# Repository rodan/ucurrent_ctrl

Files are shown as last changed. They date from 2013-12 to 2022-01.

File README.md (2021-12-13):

## µCurrent controller

a MSP430F5510 based project that controls the power delivery to Dave L. Jones's [µCurrent](https://www.eevblog.com/projects/ucurrent/)

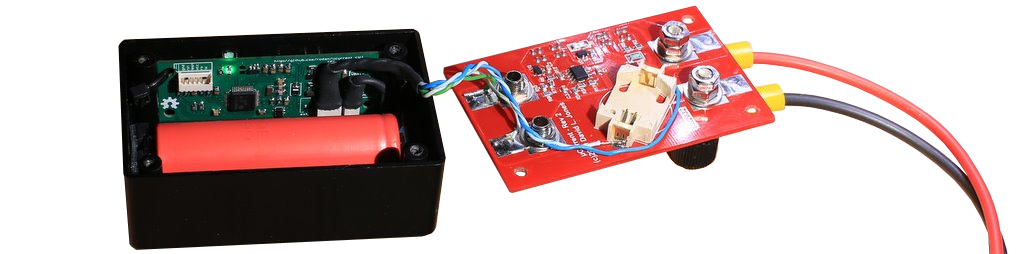
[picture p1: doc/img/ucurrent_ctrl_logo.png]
Lib Logo


```
 homepage:        https://github.com/rodan/ucurrent_ctrl
 author:          Petre Rodan <2b4eda@subdimension.ro>
 license:         GNU GPLv3
```

if you forget to turn off the original µCurrent you will find the enclosed 2032 Li cell completely flat the next day.
this project provides a timeout feature to it. a push-button is used to start up both this circuit and the µCurrent.
multiple presses will either reset the timeout counter or increase the timeout period.
the initial timeout period can be optionally modified via a 3V serial uart.
also in case the output voltage is low enough for a given period the µCurrent is turned off.

### uC pinout:

* P1.1  IN  digital - push button trigger
* P1.4  OUT digital - power-latch my circuit
* P1.5  OUT digital - enable power delivery to the uCurrent
* P2.0  OUT digital - blinky
* P6.0  IN  analog  - battery voltage
* P4.1  IO          - SDA (i2c for ADS1110)
* P4.2  IO          - SCL

### connectors:

* external power - either 3V Li Cell or 3.7V LiPo/Li-ion (MOLEX 0530470210)
* push button    - optional external push button tied to the case (MOLEX 0530470210)
* ucurrent power - uCurrent connections (MOLEX 0530470210)
* debug          - TI spy-bi-wire interface and serial uart for programming, debug and user input (MOLEX 0530470610)

### power:

* the uCurrent has the cell unpopulated and the power switch set to the "ON" position.
* this circuit will provide the 3V needed to the uCurent

### software requirements:

* [TI msp430 toolchain](https://www.ti.com/tool/MSP430-GCC-OPENSOURCE)
* [atlas430](https://github.com/rodan/atlas430) HAL library

### build and debug

the project is based on a [Makefile](./firmware/Makefile). **REFLIB_ROOT** defines the path to where this atlas430 repository has been cloned, **TARGET** represents the target microcontroller and [config.h](./firmware/config.h) will be automatically expanded into compilation macros (-DFOO arguments to be sent to gcc).

the makefile supports the following options:

```
# check if everything is installed and paths are correct
make envcheck

# remove the build/TARGET/ directory
make clean

# compile the project and library
# create dependency tree and source code tags
make

# burn the firmware onto the target microcontroller
make install

# perform an optional static scan of the source code 
make cppcheck    # needs dev-util/cppcheck
make scan-build  # needs sys-devel/clang +static-analyzer
```

in order to use gdb to debug the project make sure to enable the **CONFIG_DEBUG** macro in config.h and run in a terminal

```
LD_PRELOAD='/opt/atlas430/lib/libmsp430.so' mspdebug --allow-fw-update tilib gdb
```

and then start gdb from within the project directory:

```
make debug
```

commonly used gdb commands:

```
target remote localhost:2000
monitor reset
monitor erase
load build/MSP430FR5994/main.elf
b
disassemble
nexti
info registers
continue
tui enable
```

more images of the prototype are available [here](https://photos.app.goo.gl/GjHpzLgLqz9fdpvY7)

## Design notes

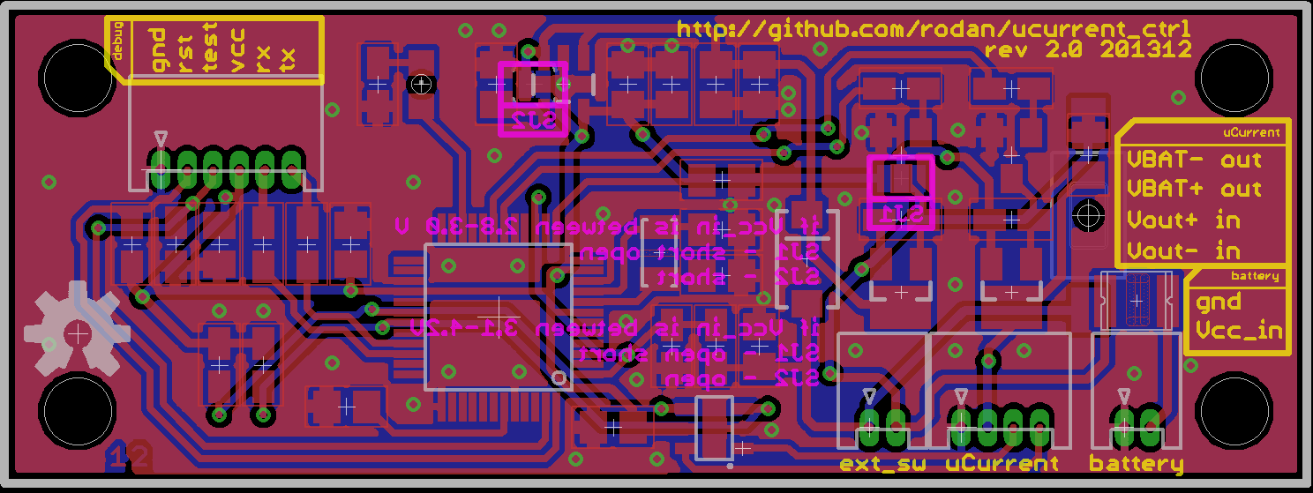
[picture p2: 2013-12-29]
hardware/board.png

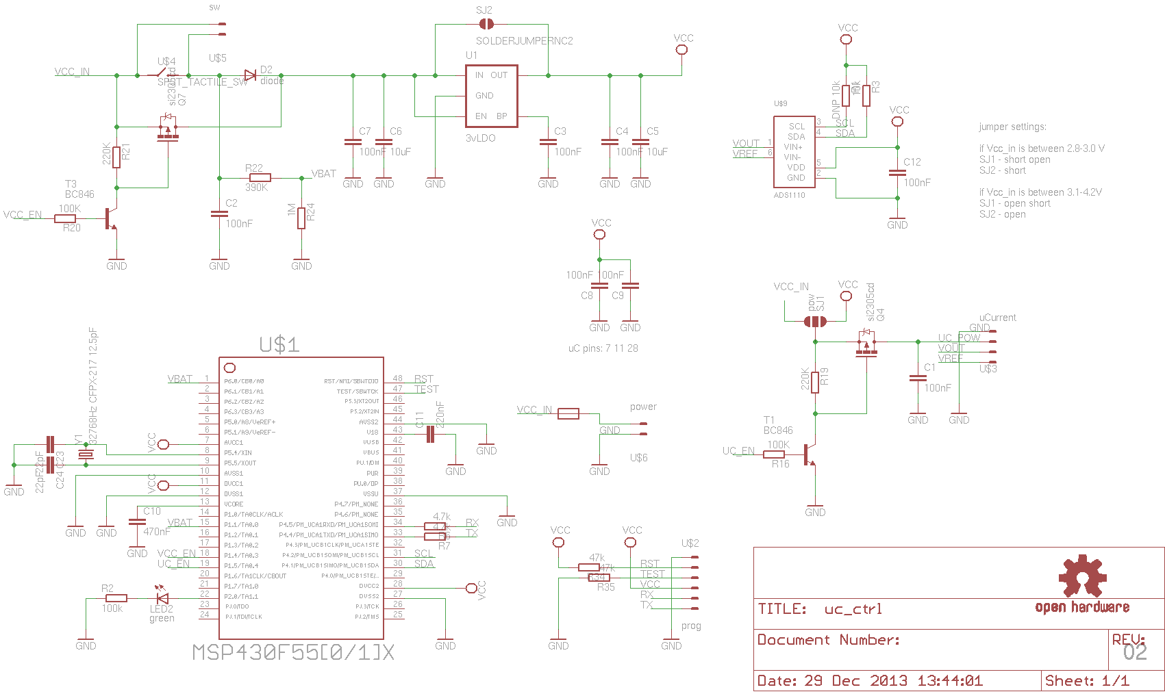
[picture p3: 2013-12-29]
hardware/schematic.png

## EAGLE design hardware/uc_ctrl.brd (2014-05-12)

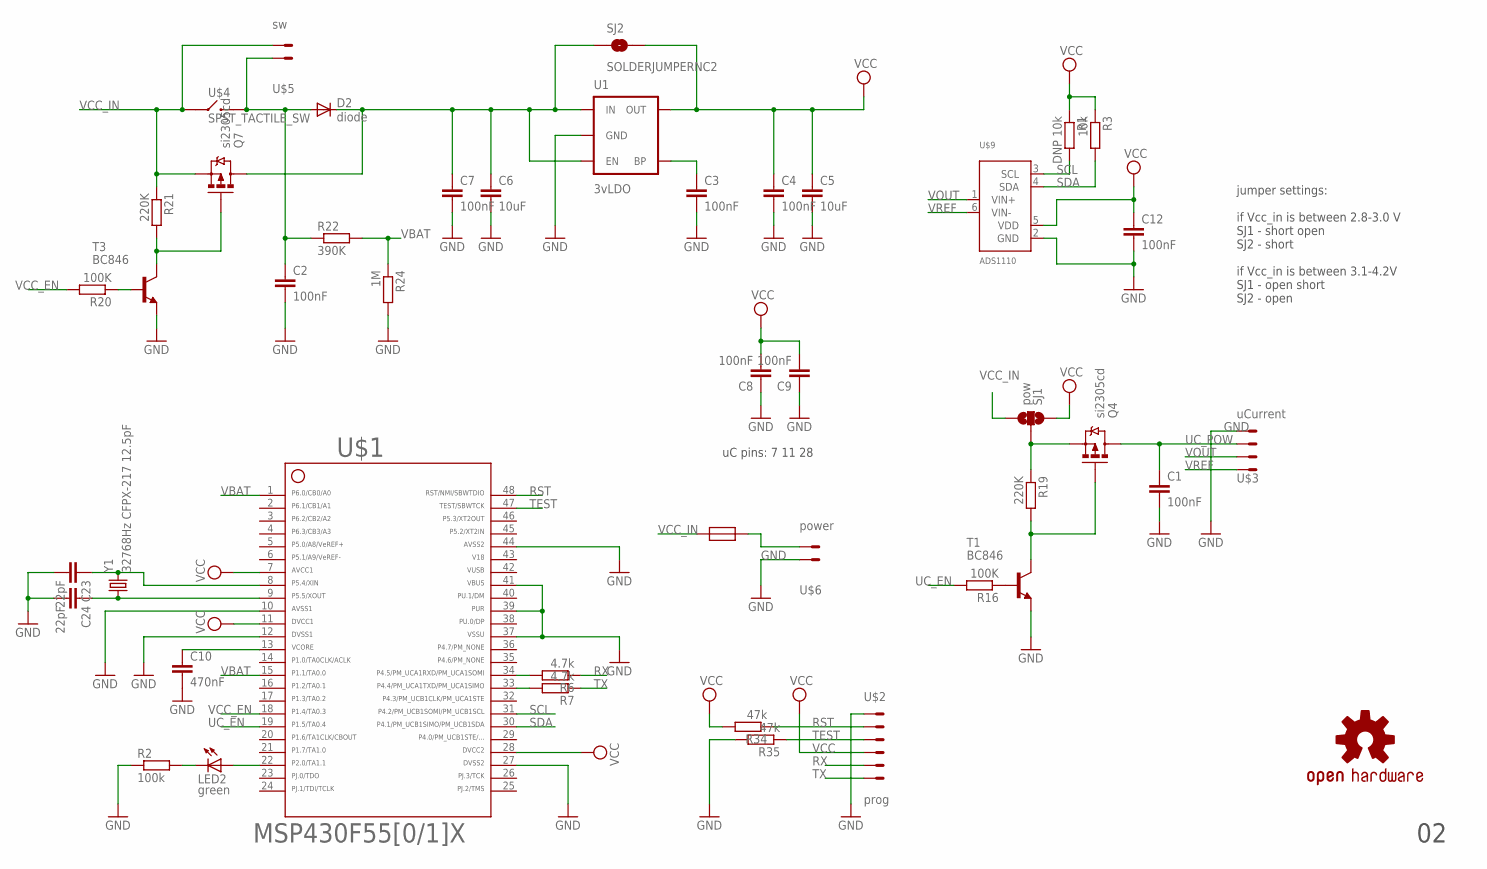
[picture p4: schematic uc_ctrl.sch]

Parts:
C1, C2, C3, C4, C7, C8, C9, C12: 100nF; C0805
C5, C6: 10uF; C0805
C10: 470nF; C0805
C23, C24: 22pF; C0805
D2: diode; SMA-DIODE
LED2: green; CHIPLED_0805
Q4, Q7: si2305cd; SOT23-3_POWER
R1: DNP 10k; R0805W
R2: 100k; R0805W
R3: 10k; R0805W
R6, R7: 4.7k; R0805W
R16, R20: 100K; R0805W
R19, R21: 220K; R0805W
R22: 390K; R0805W
R24: 1M; R0805W
R34, R35: 47k; R0805W
SJ1: pow; SJ_3_PASTE1&2
SJ2: SOLDERJUMPERNC2; SJ_2S-NOTRACE
T1, T3: BC846; SOT23
U1: 3vLDO; SOT23-5
U$1: F55[0/1]X---PT48; PT48
U$2: prog; 0530480610
U$3: uCurrent; 0530480401
U$4: SPST_TACTILE_SW; 6X3.5_TACTILE_SW
U$5: sw; 0530480210
U$6: power; 0530480210
U$7: OSHW-LOGOM; OSHW-LOGO-M
U$8: RESETTABLE; 1210
U$9: ADS1110; SOT23-6
Y1: 32768Hz CFPX-217 12.5pF; CRYSTAL-SMD-3.2X1.5

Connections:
42: U$1.42
43: U$1.43
46: U$1.46
GND: C1.2, C2.2, C3.2, C4.2, C5.2, C6.2, C7.2, C8.1, C9.1, C10.2, C12.2, C23.2, C24.2, R2.1, R24.2, R35.2, T1.2 (E), T3.2 (E), U1.2 (GND), U$1.10, U$1.12, U$1.27, U$1.37, U$1.39, U$1.41, U$1.44, U$2.1, U$3.1, U$6.P$1 (1), U$9.2 (GND)
unnamed: LED2.C, R2.2
unnamed: LED2.A, U$1.22
unnamed: R16.1, T1.1 (B)
unnamed: C6.1, C7.1, D2.C, Q7.3 (D), SJ2.1, U1.1 (IN), U1.3 (EN)
unnamed: C3.1, U1.4 (BP)
unnamed: C10.1, U$1.13
unnamed: Q4.2 (S), R19.1, SJ1.2
unnamed: U$6.P$2 (2), U$8.P$2
unnamed: R6.2, U$1.34
unnamed: R7.2, U$1.33
unnamed: C24.1, U$1.9, Y1.P$1 (1)
unnamed: C23.1, U$1.8, Y1.P$2 (2)
unnamed: Q4.1 (G), R19.2, T1.3 (C)
unnamed: R20.1, T3.1 (B)
unnamed: Q7.1 (G), R21.2, T3.3 (C)
PUSH: C2.1, D2.A, R22.1, U$4.2, U$5.P$1 (1)
RST: R34.1, U$1.48, U$2.2
RX: R6.1, U$2.5
SCL: R1.2, U$1.31, U$9.3 (SCL)
SDA: R3.2, U$1.30, U$9.4 (SDA)
TEST: R35.1, U$1.47, U$2.3
TX: R7.1, U$2.6
UC_EN: R16.2, U$1.19
UC_POW: C1.1, Q4.3 (D), U$3.2
VBAT: R22.2, R24.1, U$1.1, U$1.15
VCC: C4.1, C5.1, C8.2, C9.2, C12.1, R1.1, R3.1, R34.2, SJ1.1, SJ2.2, U1.5 (OUT), U$1.7, U$1.11, U$1.28, U$2.4, U$9.5 (VDD)
VCC_EN: R20.2, U$1.18
VCC_IN: Q7.2 (S), R21.1, SJ1.3, U$4.1, U$5.P$2 (2), U$8.P$1
VOUT: U$3.3, U$9.1 (VIN+)
VREF: U$3.4, U$9.6 (VIN-)

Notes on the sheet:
uC pins: 7 11 28
jumper settings: if Vcc_in is between 2.8-3.0 V SJ1 - short open SJ2 - short if Vcc_in is between 3.1-4.2V SJ1 - open short SJ2 - open

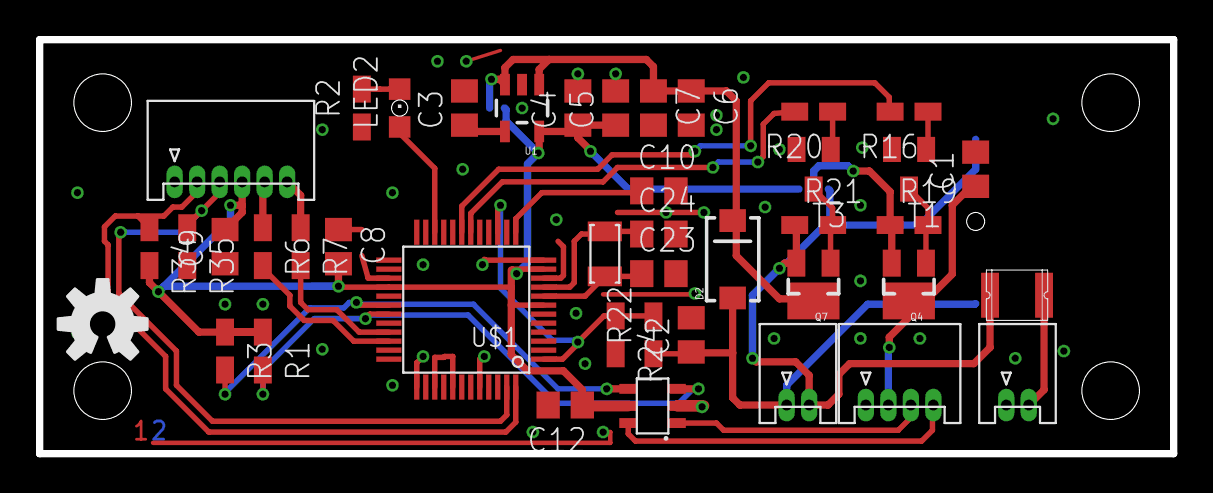
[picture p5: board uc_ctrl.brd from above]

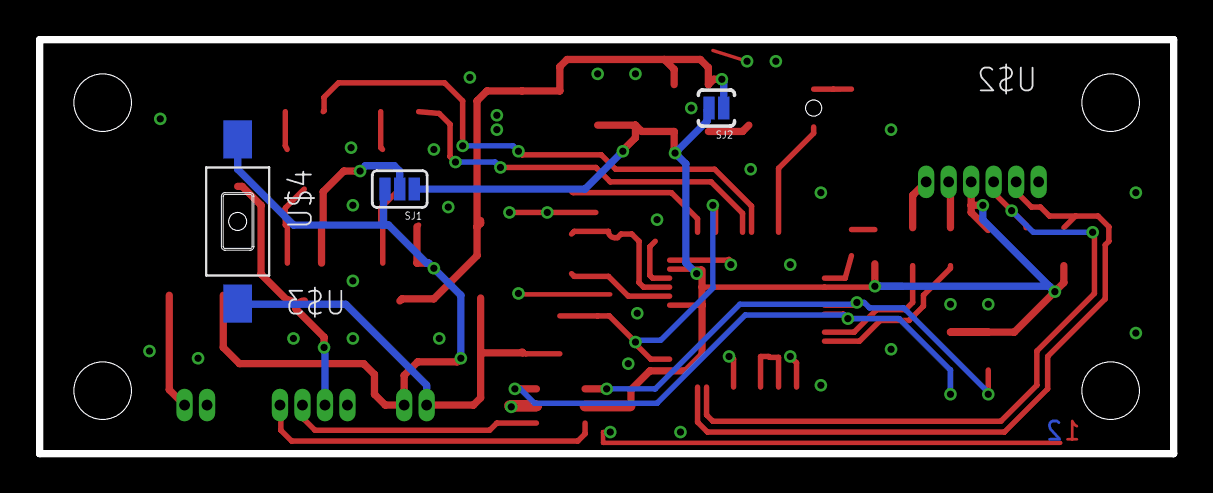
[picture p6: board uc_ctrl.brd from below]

Board: 2 copper layers, 63.0 x 23.0 mm, 45 parts (3 on the bottom side), 31 nets.

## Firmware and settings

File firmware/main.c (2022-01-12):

#include <msp430.h>
#include <stdio.h>
#include <string.h>
#include "proj.h"
#include "driverlib.h"
#include "glue.h"
#include "ui.h"
#include "sig.h"
#include "timer_a2.h"

#ifdef USE_ADC
extern struct ads1110_t eadc;
#endif

volatile uint8_t port1_last_event;
struct settings_t s;
uart_descriptor bc; // backchannel uart interface

static void uart_bcl_rx_irq(uint32_t msg)
{
    parse_user_input();
    uart_set_eol(&bc);
}

static void scheduler_irq(uint32_t msg)
{
    timer_a2_scheduler_handler();
}

void check_events(void)
{
    uint16_t msg = SYS_MSG_NULL;
    uint16_t ev;

    // uart RX
    if (uart_get_event(&bc) == UART_EV_RX) {
        msg |= SYS_MSG_UART_BCL_RX;
        uart_rst_event(&bc);
    }
    // timer_a2
    ev = timer_a2_get_event();
    if (ev) {
        if (ev & TIMER_A2_EVENT_CCR1) {
            msg |= SYS_MSG_TIMERA2_CCR1;
        }
        timer_a2_rst_event();
    }
    // timer_a2-based scheduler
    ev = timer_a2_get_event_schedule();
    if (ev) {
        if (ev & (1 << SCHEDULE_PB_11)) {
            msg |= SYS_MSG_P11_TMOUT_INT;
        }
        if (ev & (1 << SCHEDULE_ADC_SM)) {
            msg |= SYS_MSG_SCH_ADC_SM_INT;
        }
        if (ev & (1 << SCHEDULE_PS_HALT)) {
            msg |= SYS_MSG_SCH_PS_HALT_INT;
        }
        timer_a2_rst_event_schedule();
    }
    // button presses
    if (port1_last_event) {
        msg |= SYS_MSG_P11_INT;
        port1_last_event = 0;
    }

    eh_exec(msg);
}

#ifdef USE_ADC
static void ads1110_state_machine(const uint32_t msg)
{
    if (!s.eadc_en) {
        return;
    }

    switch (eadc.state) {
        case ADS1110_STATE_CONVERT:
            // conversion should be ready
            led_switch;
            ADS1110_read(I2C_BASE_ADDR, ADS1110_ED0, &eadc);
            ADS1110_convert(&eadc);
            eadc.state = ADS1110_STATE_STANDBY;
            timer_a2_set_trigger_slot(SCHEDULE_ADC_SM, systime() + 100, TIMER_A2_EVENT_ENABLE);
        break;
        case ADS1110_STATE_STANDBY:
        default:
            // trigger new single conversion
            ADS1110_config(I2C_BASE_ADDR, ADS1110_ED0, ADS1110_BITS_16 | ADS1110_PGA_2 | ADS1110_SC | ADS1110_ST);
            eadc.state = ADS1110_STATE_CONVERT;
            timer_a2_set_trigger_slot(SCHEDULE_ADC_SM, systime() + 10, TIMER_A2_EVENT_ENABLE);
        break;
    }
}
#endif

static void halt_irq(const uint32_t msg)
{
    uc_disable;
    latch_disable;
}

static void button_11_irq(const uint32_t msg)
{
    if (P1IN & TRIG1) {
        timer_a2_set_trigger_slot(SCHEDULE_PB_11, systime() + 100, TIMER_A2_EVENT_ENABLE);
        //uart_print(&bc, "PB11 short 1\r\n");
    } else {
        timer_a2_set_trigger_slot(SCHEDULE_PB_11, 0, TIMER_A2_EVENT_DISABLE);
        timer_a2_set_trigger_slot(SCHEDULE_PS_HALT, systime() + ((uint32_t) s.standby_time * 100), TIMER_A2_EVENT_ENABLE);
        uart_print(&bc, "PB11 short\r\n");
    }
}

static void button_11_long_press_irq(uint32_t msg)
{
    // ignore next edge
    P1IES &= ~TRIG1;
    P1IFG &= ~TRIG1;
    //uart_print(&bc, "PB11 long\r\n");
    display_menu();
}

void i2c_init(void)
{
    i2c_pin_init();

#if I2C_USE_DEV > 3
    // enhanced USCI capable microcontroller
    EUSCI_B_I2C_initMasterParam param = {0};

    param.selectClockSource = EUSCI_B_I2C_CLOCKSOURCE_SMCLK;
    param.i2cClk = SMCLK_FREQ;
    param.dataRate = EUSCI_B_I2C_SET_DATA_RATE_400KBPS;
    param.byteCounterThreshold = 0;
    param.autoSTOPGeneration = EUSCI_B_I2C_NO_AUTO_STOP;
    EUSCI_B_I2C_initMaster(I2C_BASE_ADDR, &param);
#elif I2C_USE_DEV < 4
    // USCI capable microcontroller
    USCI_B_I2C_initMasterParam param = {0};

    param.selectClockSource = USCI_B_I2C_CLOCKSOURCE_SMCLK;
    param.i2cClk = SMCLK_FREQ;
    param.dataRate = USCI_B_I2C_SET_DATA_RATE_400KBPS;
    USCI_B_I2C_initMaster(I2C_BASE_ADDR, &param);
#endif

    i2c_irq_init(I2C_BASE_ADDR);
}

void sys_init()
{
    // watchdog triggers after 25sec when not cleared
#ifdef USE_WATCHDOG
    WDTCTL = WDTPW + WDTIS__512K + WDTSSEL__ACLK + WDTCNTCL;
#else
    WDTCTL = WDTPW + WDTHOLD;
#endif

    /// P1.1 is VBAT (button press detect)
    P1DIR &= ~TRIG1;
    // IRQ triggers on rising edge
    P1IES &= ~TRIG1;
    // Reset IRQ flags
    P1IFG &= ~TRIG1;
    // Enable button interrupts
    P1IE |= TRIG1;

#ifndef USE_ADC
    // P4.1,P4.2 are i2c with external pullups
    P4OUT = 0x6;
#endif

    // P6.0 is VBAT in (A0)
    P6SEL |= BIT0;
    P6DIR &= ~BIT0;

    // disable VUSB LDO and SLDO
    USBKEYPID = 0x9628;
    USBPWRCTL &= ~(SLDOEN + VUSBEN);
    USBKEYPID = 0x9600;
}

void settings_init(void)
{
    uint8_t *src_p, *dst_p;
    uint8_t i;

    src_p = FLASH_ADDR;
    dst_p = (uint8_t *) & s;
    if ((*src_p) != FLASH_VER) {
        src_p = (uint8_t *) & defaults;
    }
    for (i = sizeof(s); i > 0; i--) {
        *dst_p++ = *src_p++;
    }
}

int main(void)
{
    // stop watchdog
    WDTCTL = WDTPW | WDTHOLD;
    msp430_hal_init(HAL_GPIO_DIR_OUTPUT | HAL_GPIO_OUT_LOW);
    sys_init();
#ifdef USE_SIG
    sig0_on;
#endif

    clock_pin_init();
    clock_init();

    timer_a2_init();

    bc.baseAddress = USCI_A1_BASE;
    bc.baudrate = BAUDRATE_57600;
    uart_pin_init(&bc);
    uart_init(&bc);
#if defined UART_RX_USES_RINGBUF
    uart_set_rx_irq_handler(&bc, uart_rx_ringbuf_handler);
#else
    uart_set_rx_irq_handler(&bc, uart_rx_simple_handler);
#endif

#ifdef USE_ADC
    i2c_init();
    ADS1110_init(I2C_BASE_ADDR, ADS1110_ED0, ADS1110_BITS_16 | ADS1110_PGA_2 | ADS1110_SC | ADS1110_ST);
#endif

    settings_init();
    latch_enable;
    uc_enable;

#ifdef USE_SIG
    sig0_off;
    sig1_off;
    sig2_off;
    sig3_off;
    sig4_on;
    sig5_off;
#endif

    eh_init();
    eh_register(&button_11_irq, SYS_MSG_P11_INT);
    eh_register(&button_11_long_press_irq, SYS_MSG_P11_TMOUT_INT);
    eh_register(&uart_bcl_rx_irq, SYS_MSG_UART_BCL_RX);
    eh_register(&scheduler_irq, SYS_MSG_TIMERA2_CCR1);
    eh_register(&halt_irq, SYS_MSG_SCH_PS_HALT_INT);
#ifdef USE_ADC
    eh_register(&ads1110_state_machine, SYS_MSG_SCH_ADC_SM_INT);
#endif
    timer_a2_set_trigger_slot(SCHEDULE_PS_HALT, systime() + ((uint32_t) s.standby_time * 100), TIMER_A2_EVENT_ENABLE);
    timer_a2_set_trigger_slot(SCHEDULE_ADC_SM, systime() + 100, TIMER_A2_EVENT_ENABLE);

    _BIS_SR(GIE);

    led_on;
    display_version();

    while (1) {
        // sleep
#ifdef USE_SIG
        sig4_off;
#endif
        _BIS_SR(LPM1_bits + GIE);
        __no_operation();
#ifdef USE_WATCHDOG
        WDTCTL = (WDTCTL & 0xff) | WDTPW | WDTCNTCL;
#endif
#ifdef USE_SIG
        sig4_on;
#endif
        check_events();
        check_events();
        check_events();
    }

}


// Port 1 interrupt service routine
#if defined(__TI_COMPILER_VERSION__) || defined(__IAR_SYSTEMS_ICC__)
#pragma vector=PORT1_VECTOR
__interrupt void Port_1(void)
#elif defined(__GNUC__)
__attribute__ ((interrupt(PORT1_VECTOR)))
void Port1_ISR(void)
#else
#error Compiler not supported!
#endif
{
    if (P1IFG & TRIG1) {
        port1_last_event = 1;
        // listen for opposite edge
        P1IES ^= TRIG1;
        _BIC_SR_IRQ(LPM3_bits);
    }
        
    P1IFG = 0;
}

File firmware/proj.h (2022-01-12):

#ifndef __PROJ_H__
#define __PROJ_H__

#include <msp430.h>
#include "flash.h"

#define true                1
#define false               0

/*!
	\brief List of possible message types for the event handler.
	\sa eh_register()
*/
#define           SYS_MSG_NULL  0
#define   SYS_MSG_TIMERA2_CCR1  0x10  // scheduler
#define        SYS_MSG_P11_INT  0x20  // button press
#define  SYS_MSG_P11_TMOUT_INT  0x40  // long button press
#define    SYS_MSG_UART_BCL_RX  0x80  // UART received something
#define SYS_MSG_SCH_ADC_SM_INT  0x100 // advance ADC conversion state machine 
#define SYS_MSG_SCH_PS_HALT_INT 0x200 // power saving wants to halt everything

#define         SCHEDULE_PB_11  TIMER_A2_SLOT_0  // button scheduler
#define        SCHEDULE_ADC_SM  TIMER_A2_SLOT_1  // state machine that controls the ADC conversion
#define       SCHEDULE_PS_HALT  TIMER_A2_SLOT_2  // power saving 'halt' operation
//#define                       TIMER_A2_SLOT_3
//#define                       TIMER_A2_SLOT_4
//#define                       TIMER_A2_SLOT_5
//#define                       TIMER_A2_SLOT_6
//#define                       TIMER_A2_SLOT_7
//#define                       TIMER_A2_SLOT_8

// button
#define                  TRIG1  BIT1
#define              FLASH_VER  2 // must be incremented if struct settings_t changes
#define             FLASH_ADDR  SEGMENT_B

#define latch_enable        P1OUT |= BIT4
#define latch_disable       P1OUT &= ~BIT4
#define uc_enable           P1OUT |= BIT5
#define uc_disable          P1OUT &= ~BIT5
#define led_on              P2OUT |= BIT0
#define led_off             P2OUT &= ~BIT0
#define led_switch          P2OUT ^= BIT0

struct settings_t {
    uint8_t ver;                // firmware version
    int8_t eadc_en;             // enable external adc. 0 false, 1 true, -1 false but ADS1110 present
    uint8_t adc_en;             // enable internal adc for battery check
    int16_t eadc_delta;         // 0V correction for the EADC
    uint16_t standby_time;      // number of TA0 overflows after which latch is disabled
                                // (1 overflow takes 2 seconds)
    uint16_t standby_unused;    // innactivity timeout after which latch is disabled
                                // enable_adc must be 1 for this timer to be enabled
};

static const struct settings_t defaults = {
    FLASH_VER,  // ver
    1,          // eadc_en
    0,          // adc_en
    0,          // eadc_delta
    900,        // standby_time
    600,        // standby_unused
};


#endif

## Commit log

2013-12-27 add pcb
    [uc_ctrl.brd, uc_ctrl.sch]
2013-12-27 also read uCurrent output voltage
    [uc_ctrl.brd, uc_ctrl.sch]
2013-12-28 rev 2
    [uc_ctrl.brd, uc_ctrl.sch]
2013-12-29 add 16bit adc
    [uc_ctrl.brd, uc_ctrl.sch]
2013-12-29 sent gerbers to manufacturer
    [uc_ctrl.brd, uc_ctrl.sch]
2013-12-29 add 0.5mm to board width
    [uc_ctrl.brd]
2014-01-26 add flash r/w driver
2014-01-26 add uart UI
2014-05-12 unused pin tweaks
    [uc_ctrl.brd, uc_ctrl.sch]
2019-01-12 add hardware i2c
2019-01-12 cleanup timer_a0
    [pinout.ods]
2019-01-12 adc update
2019-01-12 i2c cleanup
2019-01-13 dont blink no led
2021-12-10 rev3 redesign - skeleton stage
    [pinout.ods]
2021-12-10 stage 2 project migration
2021-12-13 adc read conflicts with uart rx
2021-12-14 uart needs LPM1 due to dependency on SMCLK
2022-01-12 uart interface changes needed by latest atlas430

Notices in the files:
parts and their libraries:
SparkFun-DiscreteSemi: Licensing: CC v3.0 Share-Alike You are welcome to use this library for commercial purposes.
